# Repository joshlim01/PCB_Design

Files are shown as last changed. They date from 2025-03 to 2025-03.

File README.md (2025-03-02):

# PCB-Design

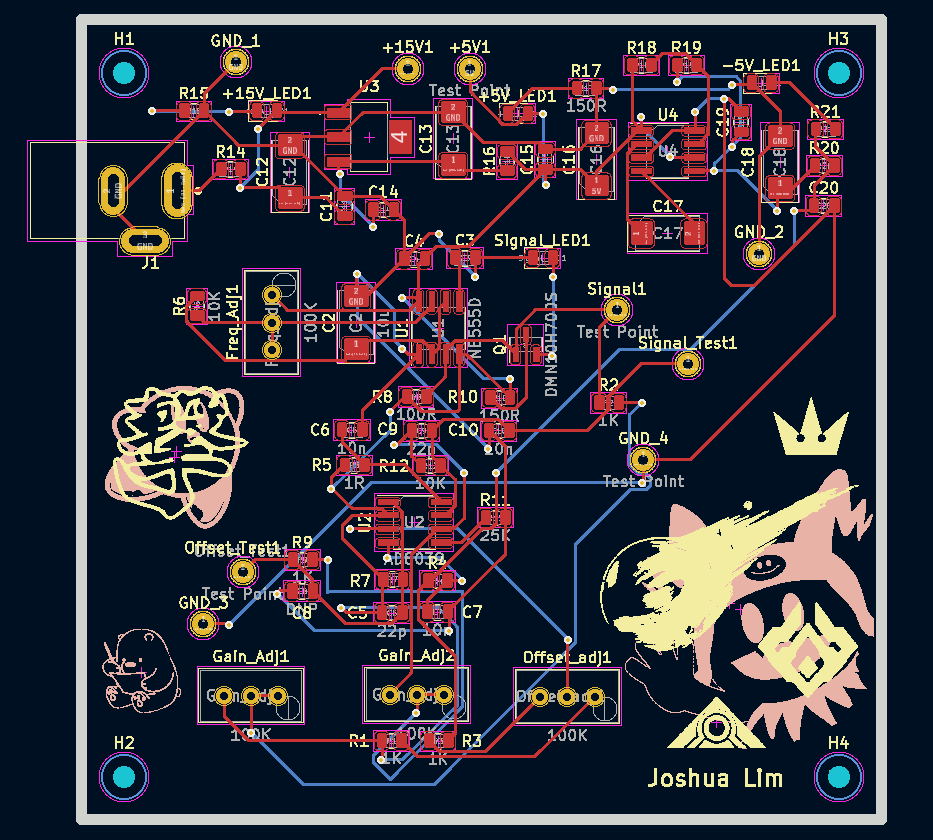
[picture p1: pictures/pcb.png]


### Files:
- PCB Course Certificate : A certificate showing completion of 30 hour PCB design course
- pcbDesign.kicad_pcb : PCB layout file in KiCAD
- signalGeneratorGerber.zip : Gerber files
- Pictures folder contains photos of the PCB design, KiCAD layout, and finished soldered board

### Description:

A signal generator PCB design project performed as part of a 30 hour course through the UBC PHAS Elab, Fall 2022.  A 15V DC signal is passed through a voltage regulator to produce 5V DC.  The 5V is passed through a 5V -> -5V converter to power the rails of an op-amp that can control output signal amplitude.  5V powers a 100kHz Timer/Oscillator that produces a squarewave signal that can be tuned in combination with the potentiometers and the op-amp.  Tuned signal can be read from a through-hole test port.

Project phases included:

#### Design
- Creating a schematic in EDA software (KiCad), including additions to the parts library.
- Creating custom component footprints to match manufacturer specifications.
- Review of good design priciples for PCB circuit layout.
- Manual layout of circuit onto a two-layer PCB, design rules specifications, variable width traces.
- Custom silk screen layering, sizing, and drill holes for ease of assembly.
- Gerber file production and PCB ordering.

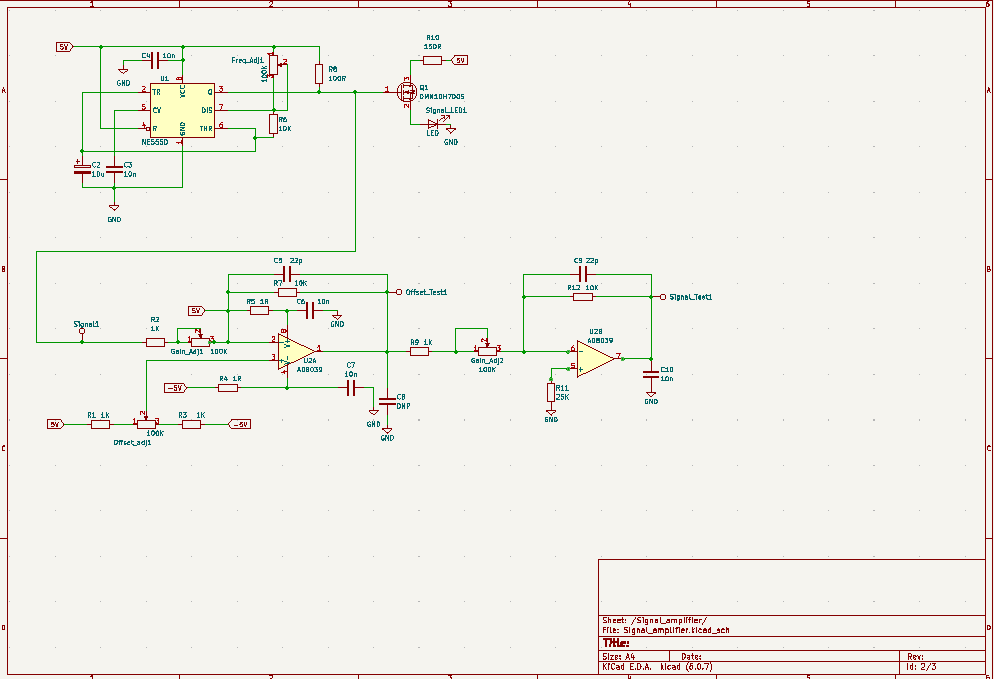
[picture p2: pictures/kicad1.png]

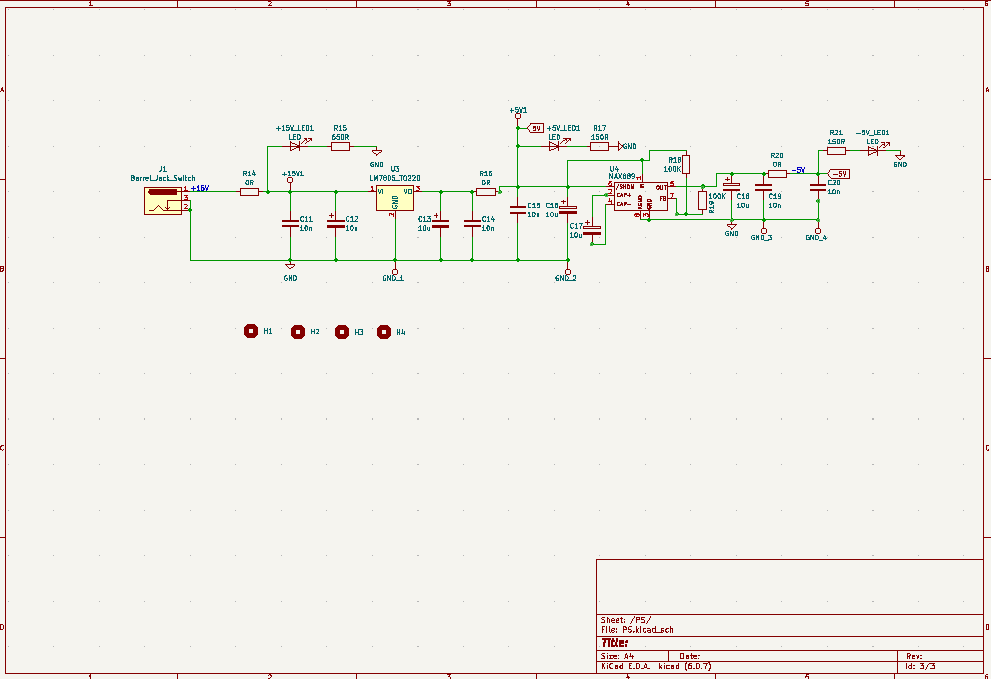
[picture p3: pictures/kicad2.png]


#### Assembly
- Manual soldering of surface mount components with a Soldering Iron Kit.
- Testing and validation with digital oscilloscope and multimeter.



### Youtube Video:

I also documented the soldering experience with a fun video and timelapse montage on Youtube. Feel free to watch it here: https://youtu.be/N-I3tIIquEQ?si=bvdNDSMJbE_GzZRB

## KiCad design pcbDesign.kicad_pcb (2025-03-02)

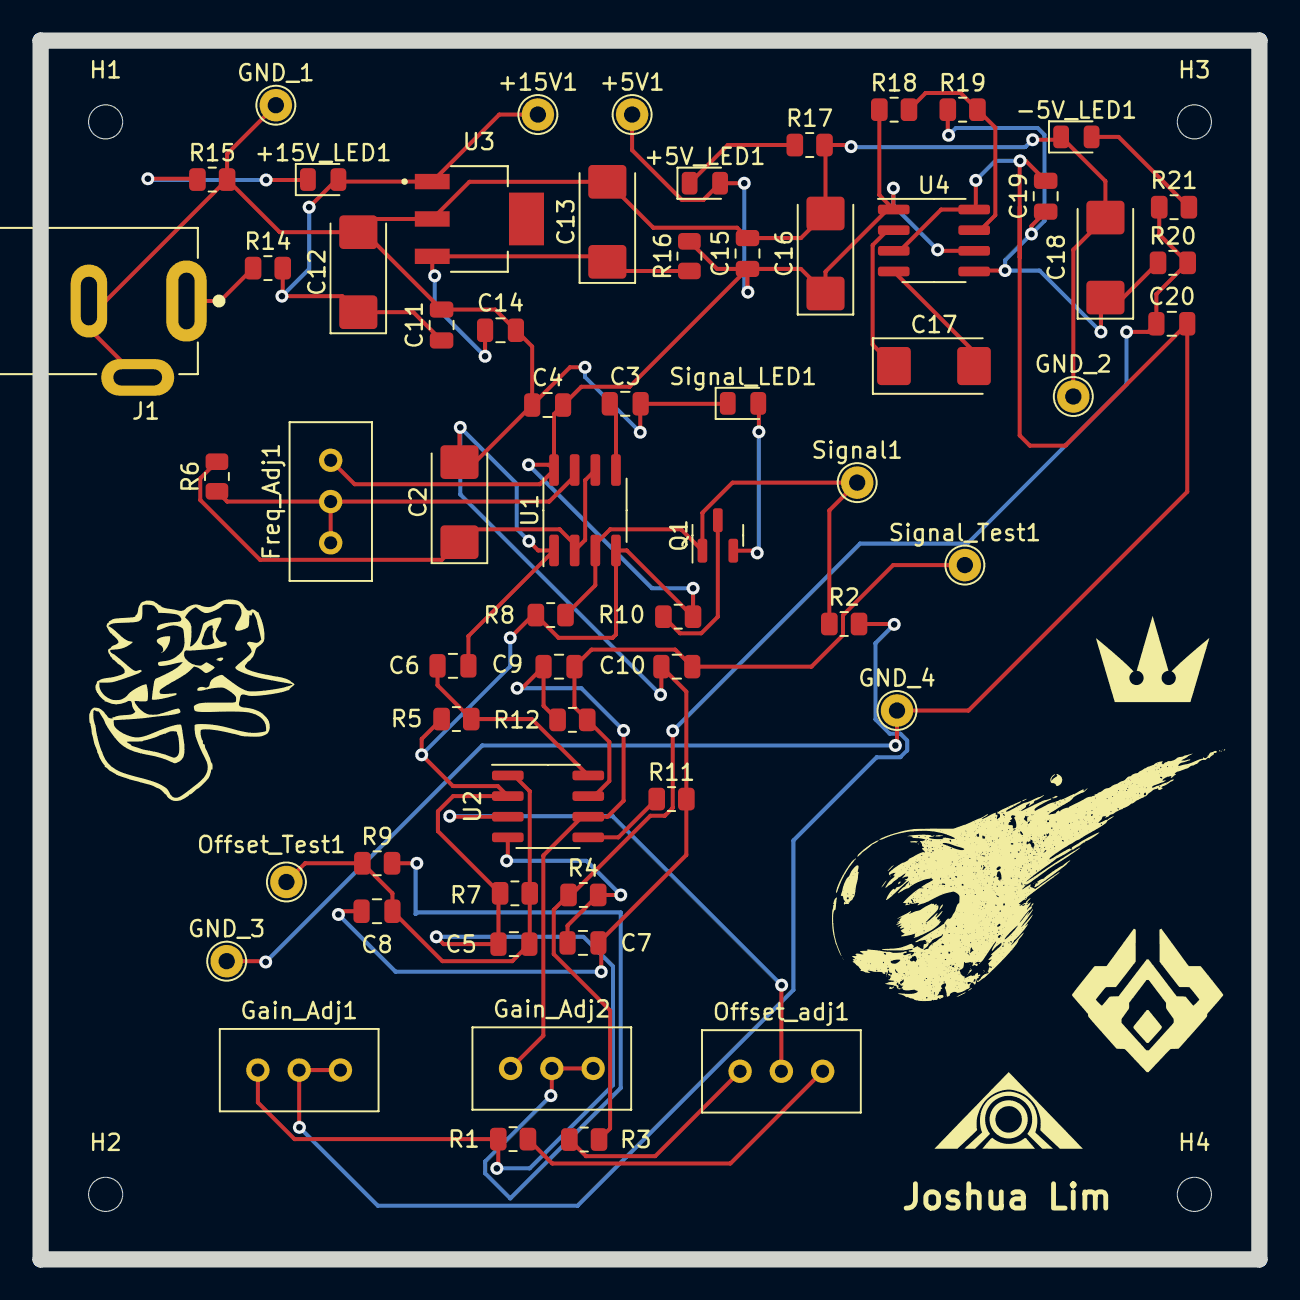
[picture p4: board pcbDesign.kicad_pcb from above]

Board: 2 copper layers, 75.0 x 75.0 mm, 66 parts (0 on the bottom side), 31 nets.

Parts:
+5V1, +15V1: Test Point; TestPoint_THTPad_D2.0mm_Drill1.0mm
+5V_LED1, +15V_LED1: LED; LED_0805_2012Metric
-5V_LED1: LED; LED_0805_2012Metric
C2, C12, C13, C16, C17, C18: 10u; CP_EIA-6032-15_Kemet-U
C3, C4, C6, C7, C10, C11, C14, C15, C19, C20: 10n; C_0805_2012Metric
C5, C9: 22p; C_0805_2012Metric
C8: DNP; C_0805_2012Metric
Freq_Adj1: 100K; Potentiometer_Bourns_3296W_Vertical
GND_1, GND_2, GND_3, GND_4: Test Point; TestPoint_THTPad_D2.0mm_Drill1.0mm
Gain_Adj1, Gain_Adj2: 100K; Potentiometer_Bourns_3296W_Vertical
H1, H2, H3, H4: MountingHole; MountingHole_2.1mm
J1: Barrel_Jack_Switch; CUI_PJ-002A
Offset_Test1: Test Point; TestPoint_THTPad_D2.0mm_Drill1.0mm
Offset_adj1: 100K; Potentiometer_Bourns_3296W_Vertical
Q1: DMN10H700S; SOT-23
R1, R2, R3, R9: 1K; R_0805_2012Metric
R4, R5: 1R; R_0805_2012Metric
R6, R7, R12: 10K; R_0805_2012Metric
R8: 100R; R_0805_2012Metric
R10, R17, R21: 150R; R_0805_2012Metric
R11: 25K; R_0805_2012Metric
R14, R16, R20: 0R; R_0805_2012Metric
R15: 650R; R_0805_2012Metric
R18, R19: 100K; R_0805_2012Metric
Signal1: Test Point; TestPoint_THTPad_D2.0mm_Drill1.0mm
Signal_LED1: LED; LED_0805_2012Metric
Signal_Test1: Test Point; TestPoint_THTPad_D2.0mm_Drill1.0mm
U1: NE555D; SOIC-8_3.9x4.9mm_P1.27mm
U2: AD8039; SOIC-8_3.9x4.9mm_P1.27mm
U3: LM7805_TO220; VREG_LM7805MPX_NOPB
U4: MAX889; SOIC-8_3.9x4.9mm_P1.27mm

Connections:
5V: +5V1.1, +5V_LED1.2 (A), C4.2, C5.1, C15.1, C16.1, Freq_Adj1.1, Gain_Adj1.3, R1.1, R5.1, R7.1, R8.1, R10.2, R16.2, R18.1, U1.4 (R), U1.8 (VCC), U2.2 (-), U4.1, U4.6
-5V: C20.1, R3.2, R4.1, R20.2, R21.1
GND: -5V_LED1.1 (K), C2.2, C3.2, C4.1, C6.2, C7.2, C8.1, C10.1, C11.2, C12.2, C13.2, C14.2, C15.2, C16.2, C18.2, GND_1.1, GND_2.1, J1.2, J1.3, R11.2, R15.2, R17.2, Signal_LED1.1 (K), U1.1 (GND), U3.2 (GND)
unnamed: +5V_LED1.1 (K), R17.1
unnamed: +15V1.1, +15V_LED1.2 (A), C11.1, C12.1, R14.2, U3.1 (VI)
unnamed: +15V_LED1.1 (K), R15.1
unnamed: -5V_LED1.2 (A), R21.2
unnamed: C2.1, R6.2, U1.2 (TR), U1.6 (THR)
unnamed: C3.1, U1.5 (CV)
unnamed: C5.2, C8.2, Offset_Test1.1, R7.2, R9.1, U2.1
unnamed: C6.1, R5.2, U2.8 (V+)
unnamed: C7.1, R4.2, U2.4 (V-)
unnamed: C9.1, Gain_Adj2.3, R12.1, U2.6 (-)
unnamed: C9.2, C10.2, R12.2, Signal_Test1.1, U2.7
unnamed: C13.1, C14.1, R16.1, U3.3 (VO)
unnamed: C17.1, U4.2
unnamed: C17.2, U4.4
unnamed: C18.1, C19.1, R19.1, R20.1, U4.5
unnamed: C19.2, C20.2, GND_3.1, GND_4.1, U4.3, U4.8
unnamed: Freq_Adj1.2, Freq_Adj1.3, R6.1, U1.7 (DIS)
unnamed: Gain_Adj1.1, Gain_Adj1.2, R2.2
unnamed: Gain_Adj2.1, Gain_Adj2.2, R9.2
unnamed: J1.1, R14.1
unnamed: Offset_adj1.1, R1.2
unnamed: Offset_adj1.2, U2.3 (+)
unnamed: Offset_adj1.3, R3.1
unnamed: Q1.1 (G), R2.1, R8.2, Signal1.1, U1.3 (Q)
unnamed: Q1.2 (S), Signal_LED1.2 (A)
unnamed: Q1.3 (D), R10.1
unnamed: R11.1, U2.5 (+)
unnamed: R18.2, R19.2, U4.7
